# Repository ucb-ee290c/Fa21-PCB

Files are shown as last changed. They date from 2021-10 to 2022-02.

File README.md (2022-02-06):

# Test PCB for EE290C Spring 2021 Tapeout Class Chip

This is the repo for the PCB. Designed in Altium designer. DRC specs set by Bay Area Circuits standard process.

Uses symbols and footprints from the BWRC libraries.

**Rev 1:** Initial PCB

**Rev 2:** Electrically the same as rev 1; several silkscreen labelling improvements and corrections to headers. Changed the SMA connector footprints to be all through-hole instead of SMD center. Production change had the vias in the FMC connector actually filled this time.

### Useful Things

*Schematic Editor*

Tools (T) -> Footprint manager: assign footprints

T->A->A: Annotate schematics

*PCB Editor*

T->M: Clear all error markers

T->G->A: Rebuild all pours

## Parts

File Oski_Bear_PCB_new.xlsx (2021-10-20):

Comment | Description | Designator | Footprint | LibRef | Quantity
0.1uF | 0.1uF 0402, 10uF 0603 | C1, C2, C3, C4, C5, C6, C8, C10, C12, C14, C16, C18, C20, C21, C23, C25, C26, C27, C30, C31, C32, C34, C45, C46, C47, C48, C49, C50, C51 | 0603 | DISCRETE_C | 29
10uF | 10uF 0603 | C7, C9, C11, C13, C15, C17, C19, C22, C24, C33, C37, C38, C44 | 0603 | DISCRETE_C | 13
10u | Capacitor generic | C28, C36 | 0603 | DISCRETE_C | 2
0.1u | Capacitor generic | C29, C35, C39 | 0603 | DISCRETE_C | 3
22p | Capacitor generic | C40 | 0603 | DISCRETE_C | 1
1n | Capacitor generic | C41 | 0603 | DISCRETE_C | 1
5.1p | Capacitor generic | C42 | 0603 | DISCRETE_C | 1
2.9p | Capacitor generic | C43 | 0603 | DISCRETE_C | 1
1nF | 0.1uF 0402 | C52, C53, C54, C55 | 0603 | DISCRETE_C | 4
DISCRETE_LED | LED generic | D1, D2, D3, D4, D5, D6, D7 | LED-1206 | DISCRETE_LED | 7
61300211121 |  | H1, H2, H4, H5, H6, H8, H9, J14 | CON-002-100-200X100/1X2-POST | 61300211121 | 8
61300621121 |  | H3, H7, J29, J30 | CON-006-100-300X200/2X3-POST | 61300621121 | 4
Con 400 pins in 10 parts: abcdefghjk VITA 57 | Con VITA 57, 400 male contacts in 10 parts abcdefghjk | J1 | CON-400-1.27-60.0X14.7/PLUG-SEARAY | CON_400pin_10x40_VITA57_PLUG | 1
Con RF SMA | Con RF SMA | J2, J5, J11, J12, J13, J18, J20, J22, J23, J24, J25, J38 | CON-001-7.0X7.0/SMT/THT-SMA-ST | CON_RF_SMA | 12
Con 1 pin | Con 1 pin | J3, J4 | CON-001-312X312/BANANA-JACK | CON_001pin_1x1 | 2
uSD card conn 5033981892 | Con 8 pins secure digital card slot (micro) | J7 | CON-008-1.1-13.1X14.0/MICROSD_MOLEX | CON_010pin_uSD_CARD_RECP | 1
Con 10 pins 2x5 | Con 10 pins 2x5 | J8 | CON-010-1.27-20.9X7.52/2X5-POST-SH-ST | CON_010pin_2x5 | 1
Con 4 pins 2x2 | Con 4 pins 2x2 | J9, J10, J15, J17, J27, J36 | CON-004-100-200X200/2X2-POST | CON_004pin_2x2 | 6
Con 10 pins 2x5 | Con 10 pins 2x5 | J16 | CON-10-100-500-200/5X2-POST | CON_010pin_2x5 | 1
Con 20 pins 2x10 | Con 20 pins 2x10 | J26 | CON-020-100-1300X340/SHR-ST | CON_020pin_2x10 | 1
Con 2 pins | Con 2 pins | J28, J31, J32, J33, J35 | CON-002-100-200X100/1X2-POST | CON_002pin_1x2 | 5
Con 6 pins 2x3 | Con 6 pins 2x3 | J34, J37 | CON-006-100-300X200/2X3-POST | CON_006pin_2x3 | 2
3.3n | Inductor generic | L1 | 0603 | DISCRETE_L | 1
3.9n | Inductor generic | L2 | 0603 | DISCRETE_L | 1
3.4n | Inductor generic | L3 | 0603 | DISCRETE_L | 1
Banana Plug |  | P1, P2, P3, P4, P5, P6, P7, P8, P9, P10 | CON-001-312X312/BANANA-JACK | Banana Plug | 10
16k | 16k | R1, R6, R7, R8 | 0603 | DISCRETE_R | 4
26.1k | 200 0402 | R2 | 0603 | DISCRETE_R | 1
12k | 200 0402 | R3 | 0603 | DISCRETE_R | 1
10k | 200 0402, [NoValue], Resistor generic | R4, R5, R10, R12, R16, R17 | 0603 | DISCRETE_R | 6
33.2 | Resistor generic | R9 | 0603 | DISCRETE_R | 1
63k | Resistor generic | R11 | 0603 | DISCRETE_R | 1
0 | 0 0603, Resistor generic | R13, R21 | 0603 | DISCRETE_R | 2
6.7k | Resistor generic | R14 | 0603 | DISCRETE_R | 1
34k | 200 0402 | R15 | 0603 | DISCRETE_R | 1
470 | 200 0402 | R18, R19, R20, R23, R24, R25, R26 | 0603 | DISCRETE_R | 7
100k | 200 0402 | R31, R32, R33, R34 | 0603 | DISCRETE_R | 4
SWITCH_SPST_4pin | Switch 4 pins | S2 | SW-04-4.50-6.0X6.7 | SWITCH_SPST_4pin | 1
575-4 | Test point | T1, T2, T7 | TP-100X100/ROUND-THT | TEST_PT | 3
Test point 1 pin | Test point 1 pin | T3, T4, T5, T6, T8, T9, T10, T11 | TP-100X100/ROUND-THT | TEST_PT | 8
MCP1726 | 1A, Low-Voltage, Low Quiescent Current LDO Regulator | U1, U2, U5, U9 | SOIC-8 | MCP1726 | 4
NLSV4T244EDTR2G | Non-Inverting Level Translator, Dual-Supply, 4-Bit | U3, U4, U6, U7, U12, U18 | TSSOP-14 | NLSV4T244EDTR2G | 6
CON_012pin_1x12 |  | U8, U16 | CON-12-100-1200-100/1X12-POST | CON_012pin_1x12 | 2
HSWA2-63DR+ | HSWA2-63DR+ RF T/R switch | U10 | QFN-20-.5-4.0X4.0 | IC_HSWA2-63DR+ | 1
MNA-6A+ | MNA-6A+ RF power amplifier | U11 | QFN-08-.65-3.0X3.0 | IC_MNA-6A+ | 1
IC_TXB0104 | 4-Bit Bidirectional Voltage-level Translator With Automatic Direction Sensing | U13 | SOIC-14 | IC_TXB0104 | 1
IC_LM234 | 3-Terminal Adjustable Current Sources | U14 | TO-92 | IC_LM234 | 1
CON_06pin_1x6 |  | U15 | CON-6-100-600-100/1X6-POST | CON_06pin_1x6 | 1
SN74LVC1G19 | 1-of-2 Decoder and Demultiplexer | U17 | SOT-23-6 | SN74LVC1G19 | 1
SOIC8_FLASH |  | UF | SOIC-8 | SOIC8_FLASH | 1
IC_OSCI_CHIP | EE290C Tapeout Class IC | UX | QFN-48-.4-6.0X6.0-LP | IC_OSCI_CHIP | 1
ECS-5032MV-200-CN | 20 MHz HCMOS Oscillator, 1.6 - 3.6V | X1 | XTAL-04-5.0X3.2 | ECS-5032MV-200-CN | 1
ECS-2520MVLC-020-BN | 2MHz CMOS Oscillator, 1.6 - 3.6V | X2 | XTAL-04-2.5X2.0 | ECS-2520MVLC-020-BN | 1

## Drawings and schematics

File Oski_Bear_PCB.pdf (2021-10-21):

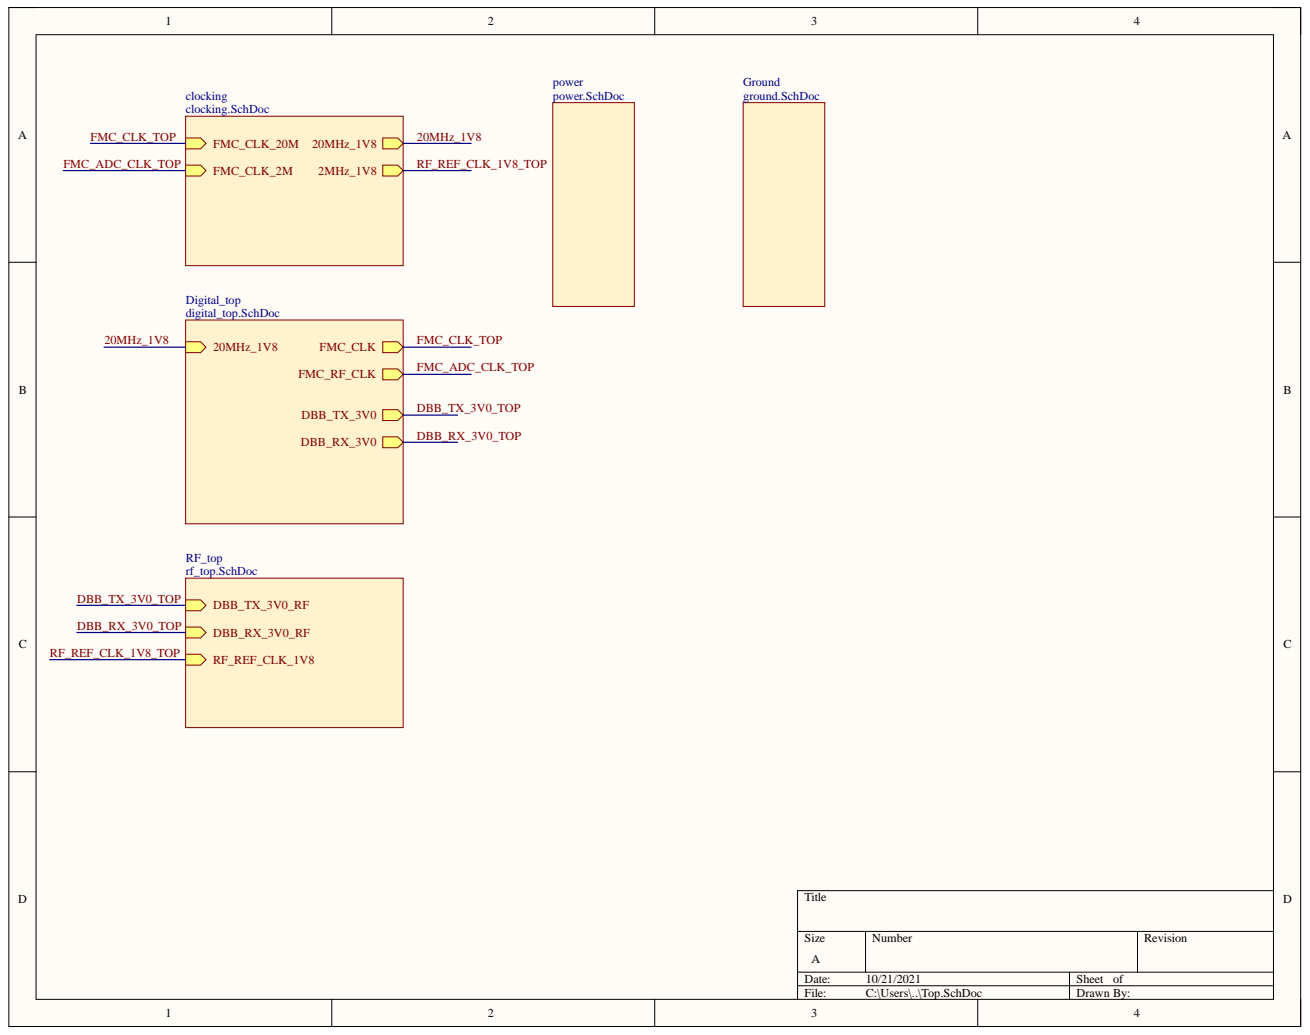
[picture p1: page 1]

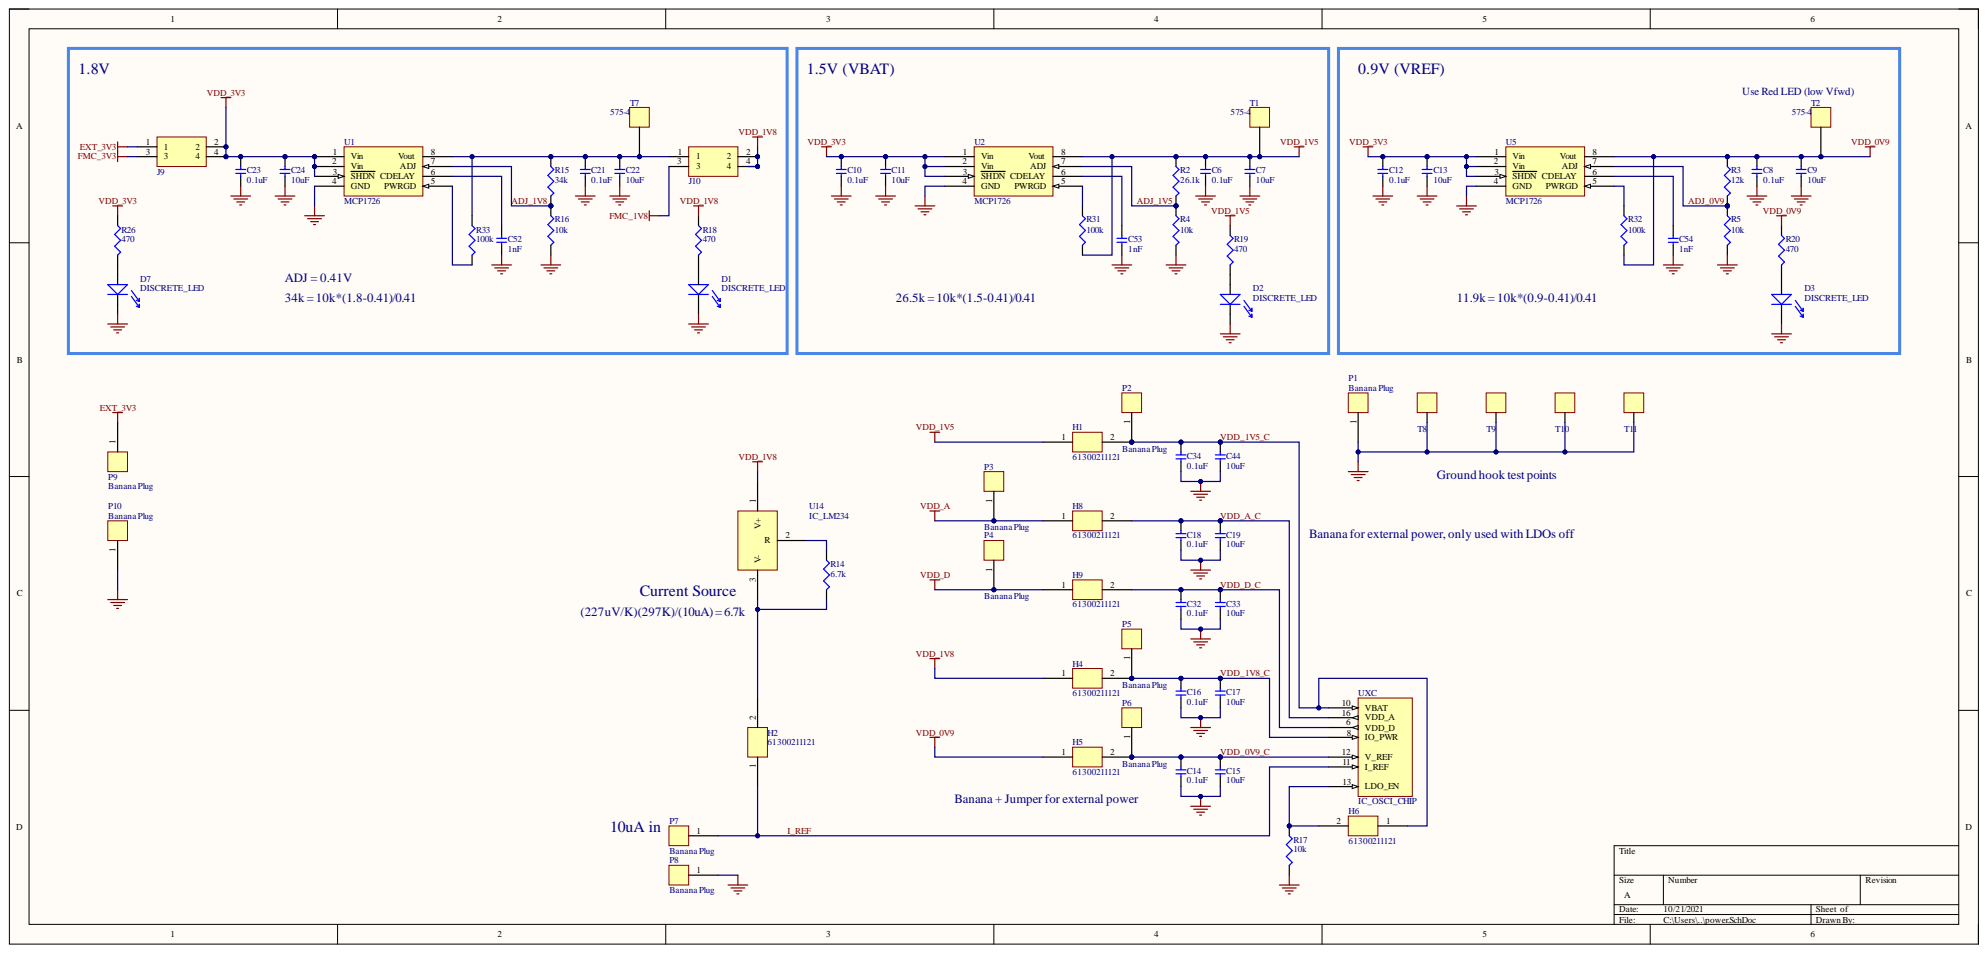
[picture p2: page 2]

Use Red LED (low Vfwd)

I_REF | 1 3

e : 1 0 / 2 1 /2 0 2 1 | S h e e t o f
F i l e : C: \ U s ers \ . . \p o w e r. S chD o c | Dra w n B y :

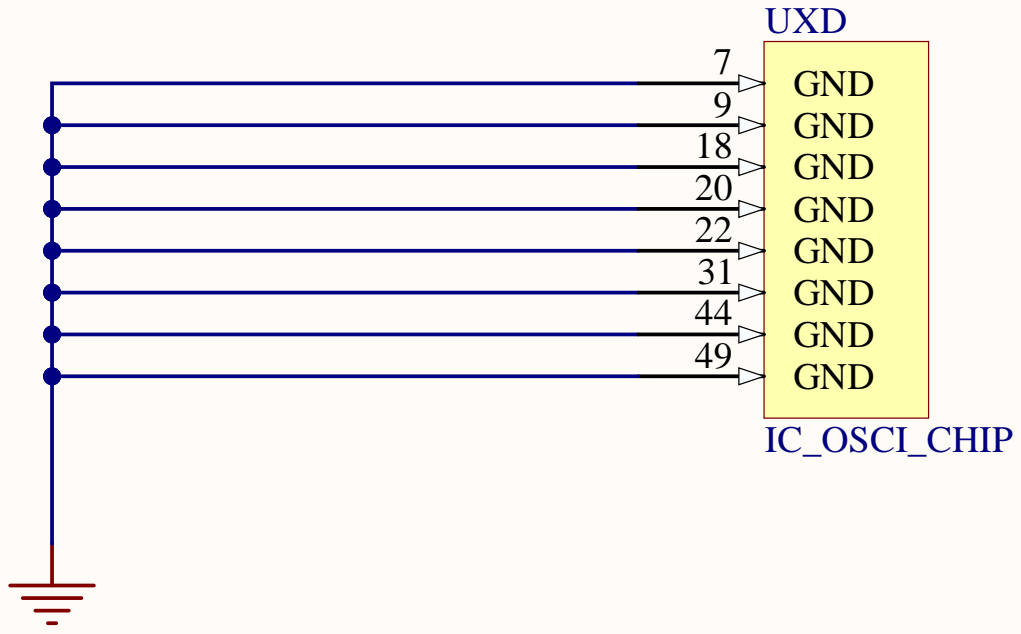
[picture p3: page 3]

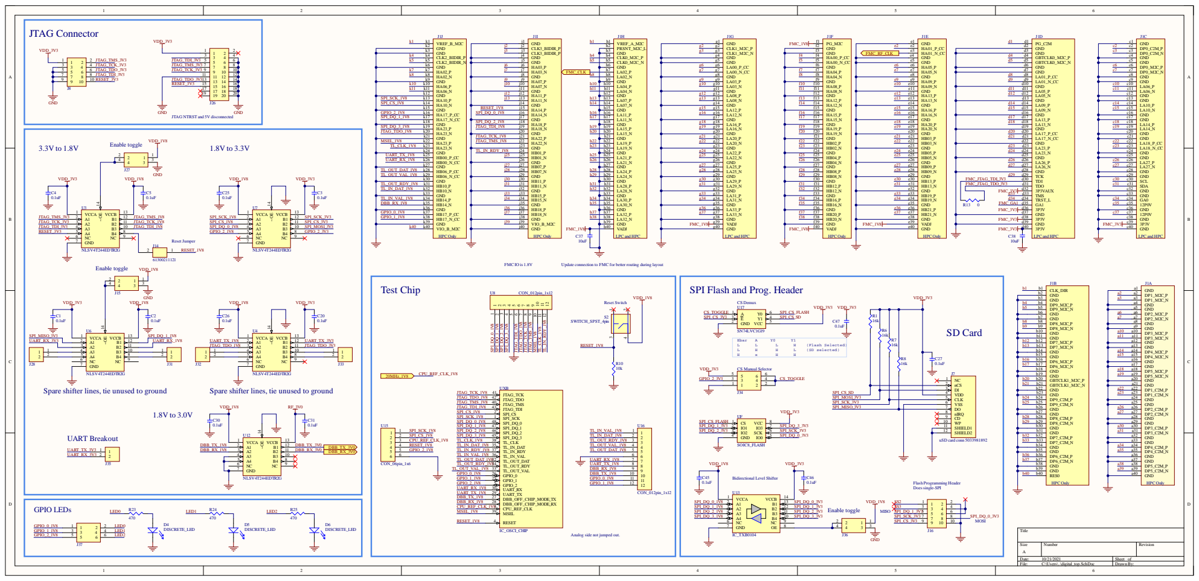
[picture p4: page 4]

Update connection to FMC for better routing during layout

SPI Flash and Prog. Header

b9 | DP8_M2C_N b9 | GND a9

Spare shifter lines, tie unused to ground

Analog side not jumped out.

Date: 10/21/2021 | Sheet of
File: C:\Users\..\digital_top.SchDoc | Drawn By:

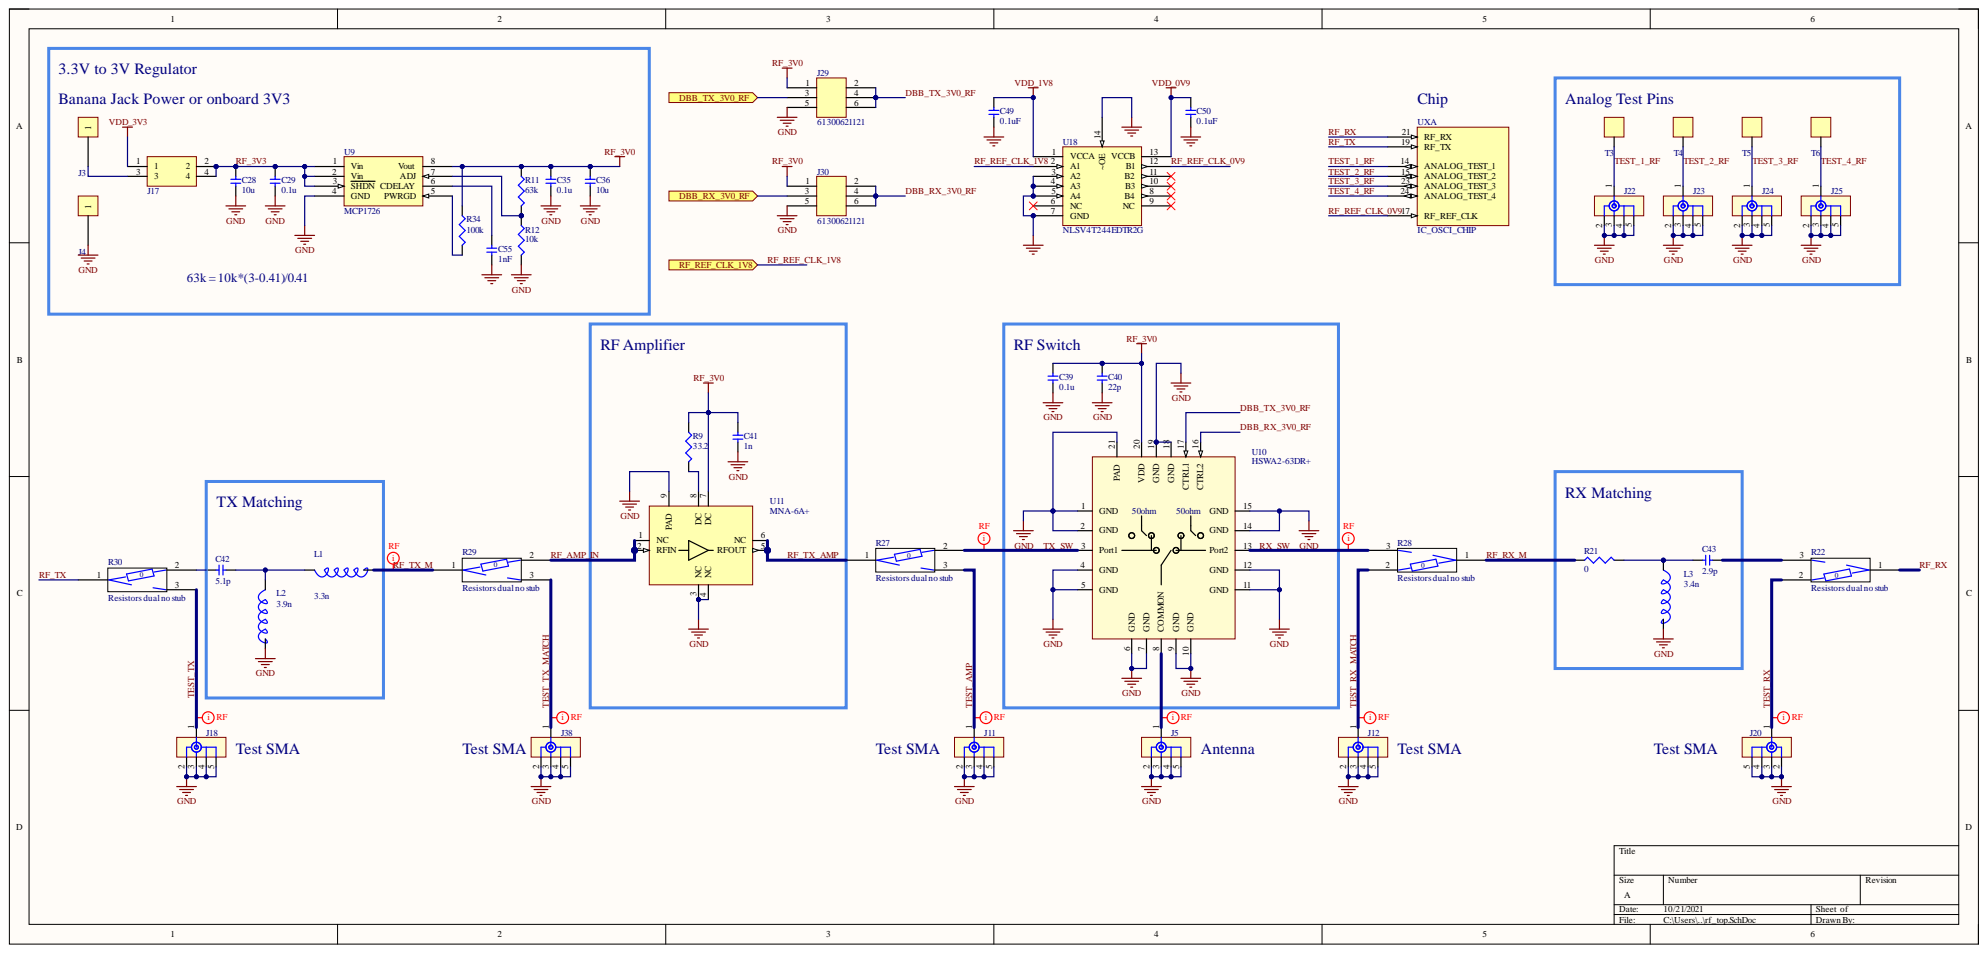
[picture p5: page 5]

Banana Jack Power or onboard 3V3

Size A | Number | Revision

Date: 10/21/2021 | Sheet of
File: C:\Users\..\rf_top.SchDoc | DrawnBy:

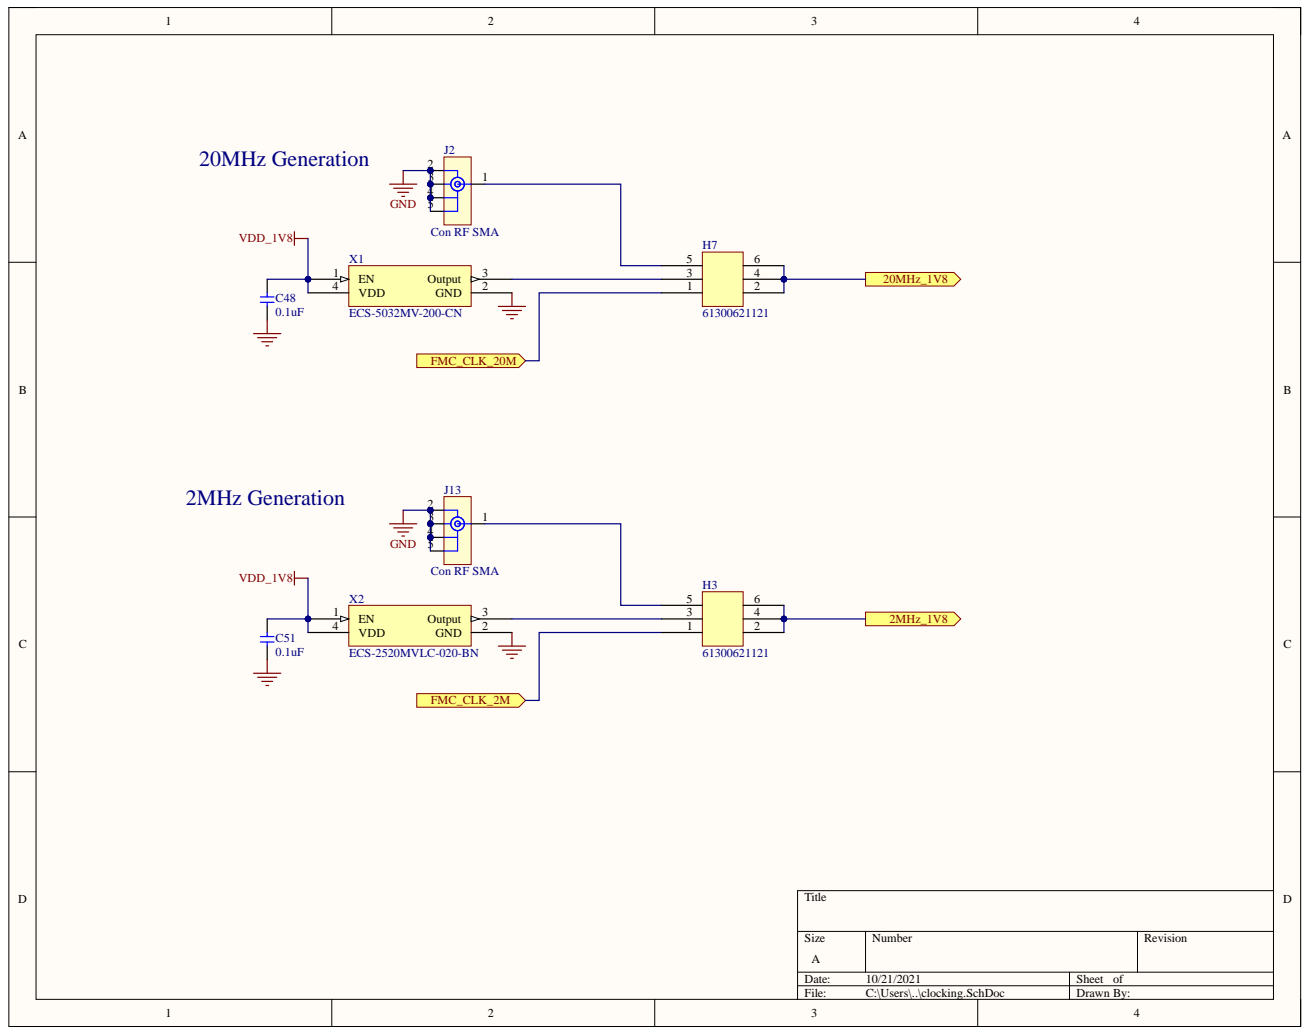
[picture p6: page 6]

EN 1 VDD 4 GND | 2 Output 3 3 | 4

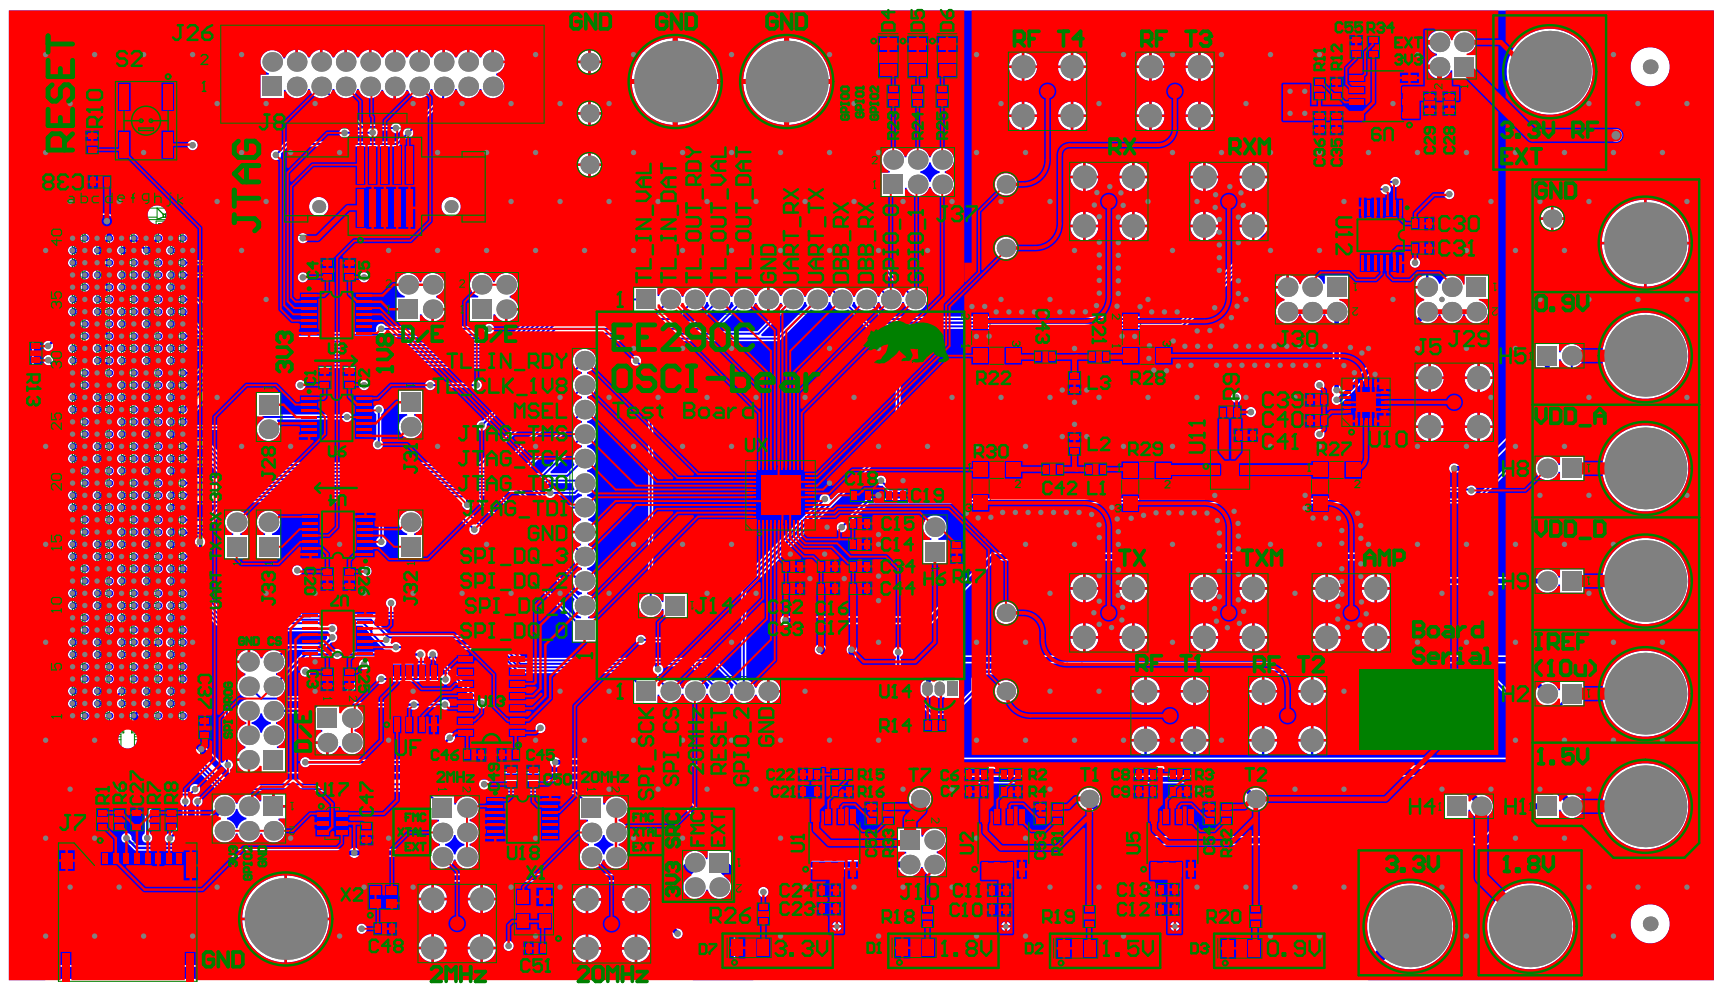
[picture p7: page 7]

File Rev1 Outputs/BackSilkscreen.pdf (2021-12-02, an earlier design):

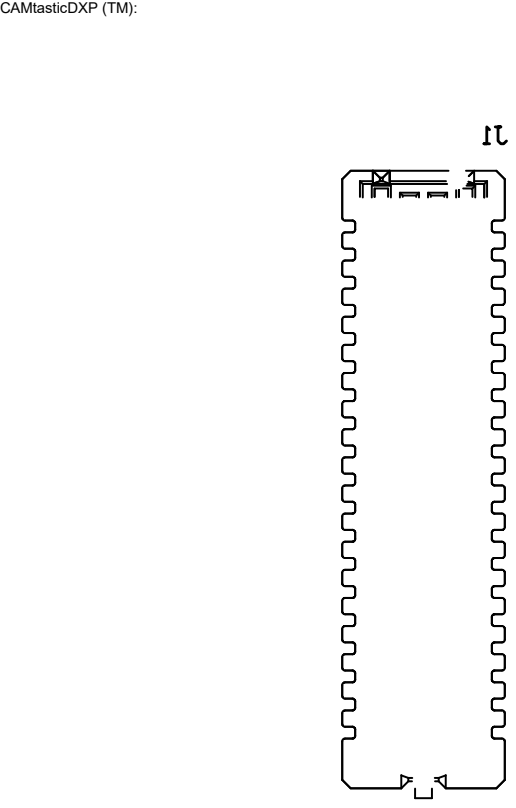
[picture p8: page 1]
CAMtasticDXP (TM):

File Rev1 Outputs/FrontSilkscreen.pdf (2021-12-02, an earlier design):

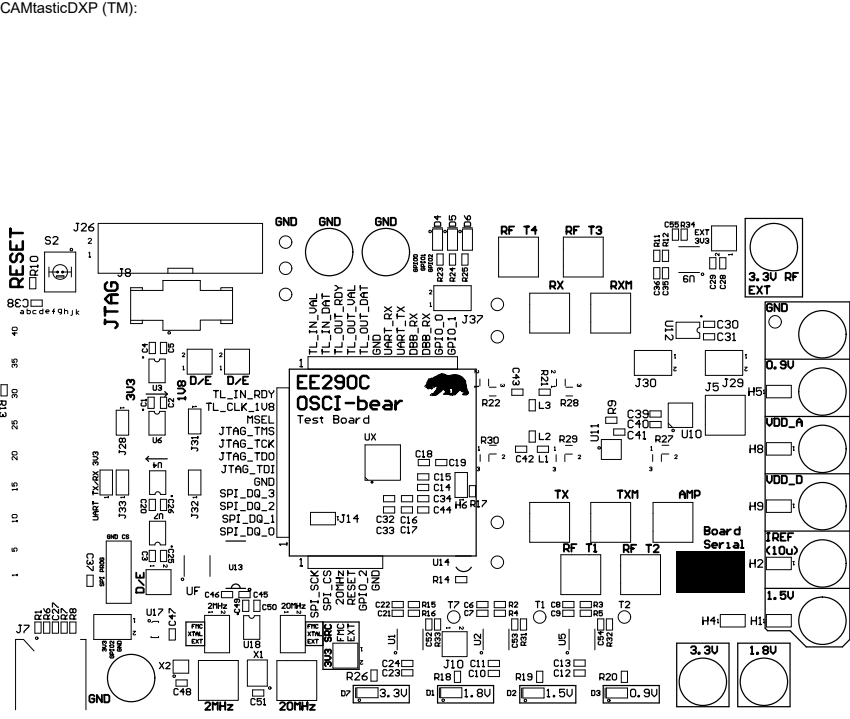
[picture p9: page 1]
CAMtasticDXP (TM):

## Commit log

2021-07-06 First cut at the Test Plan
2021-09-08 schematic updates / headers added
    [Naive.SchDoc, Oski_Bear_PCB.PrjPcb, Oski_PCB.PcbDoc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]
2021-09-12 WIP RF schematic, trying to get full PCB to be error free
    [Naive.SchDoc, Oski_Bear_PCB.PrjPcb, Oski_PCB.PcbDoc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]
2021-09-12 Resize rf_top schematic to be larger
    [rf_top.SchDoc]
2021-09-13 Aligning grid in digital_top and rf_top
    [digital_top.SchDoc, rf_top.SchDoc]
2021-09-13 Made digital_top neater, slowly working through general connectivity
    [Oski_PCB.PcbDoc, Top.SchDoc, clocking.SchDoc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]
2021-09-14 Added JTAG connector
    [Oski_PCB.PcbDoc, Top.SchDoc, clocking.SchDoc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]
2021-09-14 Added schematic.SchLib, some realignment
    [Oski_Bear_PCB.PrjPcb, clocking.SchDoc, digital_top.SchDoc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]
2021-09-15 Assign some I/O
    [digital_top.SchDoc, power.SchDoc]
2021-09-15 Consolidate chip
    [Oski_Bear_PCB.PrjPcb, digital_top.SchDoc, ground.SchDoc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]
2021-09-17 Major power, digital refactor
    [Oski_Bear_PCB.PrjPcb, Top.SchDoc, clocking.SchDoc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]
2021-09-21 Added pin headers, updated clocking
    [Oski_Bear_PCB.PrjPcb, Top.SchDoc, clocking.SchDoc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]
2021-09-22 Organize schematic
    [clocking.SchDoc, digital_top.SchDoc, power.SchDoc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]
2021-09-24 Update with changes from last review, just need the RF test now
    [Oski_Bear_PCB.PrjPcb, Top.SchDoc, digital_top.SchDoc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]
2021-09-24 Clean up digital_top
    [digital_top.SchDoc, power.SchDoc, rf_top.SchDoc]
2021-09-25 Added RF test jumpers
    [Oski_Bear_PCB.PrjPcb, digital_top.SchDoc, power.SchDoc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]
2021-10-02 Updated RF testing jumpers, almost done assigning footprints
    [Oski_Bear_PCB.PrjPcb, Oski_PCB.PcbDoc, clocking.SchDoc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]
2021-10-05 All footprints assigned, beginning layout
    [OSCI-pcb-fp.PcbLib, Oski_Bear_PCB.PrjPcb, clocking.SchDoc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]
2021-10-05 Preliminary component grouping
    [Oski_Bear_PCB.PrjPcb, Top.SchDoc, digital_top.SchDoc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]
2021-10-06 Core layout in-progress
    [digital_top.SchDoc, ground.SchDoc, power.SchDoc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]
2021-10-06 More layout of power
    [OSCI-pcb-fp.PcbLib, Oski_Bear_PCB.PrjPcb, clocking.SchDoc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]
2021-10-09 RF preliminary layout
    [OSCI-pcb-fp.PcbLib, clocking.SchDoc, rf_top.SchDoc]
2021-10-09 Arranging 2 electric boogaloo, digital a little dense rn
    [rf_top.SchDoc]
2021-10-09 More first pass routing; kinda ugly
    [digital_top.SchDoc]
2021-10-10 Routing to FMC
    [clocking.SchDoc, digital_top.SchDoc]
2021-10-10 Inital fully routed
    [digital_top.SchDoc]
2021-10-10 Actually all routed now; need to verify DRC
    [rf_top.SchDoc]
2021-10-10 More labels, added image
    [Oski_Bear_PCB.PrjPcb, Top.SchDoc]
2021-10-13 Tent vias, update sch, output BOM
    [Oski_Bear_PCB.xlsx]
2021-10-18 Update regulator, PCB is BAC DRC clean
    [OSCI-pcb-fp.PcbLib, Oski_Bear_PCB.PrjPcb, digital_top.SchDoc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]
2021-10-20 Update TXB0104 to SOIC-14
    [OSCI-pcb-fp.PcbLib, Oski_Bear_PCB.PrjPcb, Oski_Bear_PCB.xlsx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]
2021-10-21 Added vias to all FMC pins
    [Oski_Bear_PCB.PrjPcb, digital_top.SchDoc]
2021-12-02 Changed SMA to all through-hole, clarified some silkscreen
    [OSCI-pcb-fp.PcbLib, Oski_Bear_PCB.PrjPcb, clocking.SchDoc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]
2021-12-02 Export v2 gerbers
2021-12-03 Add RST silk
    [Oski_Bear_PCB.PrjPcb]
